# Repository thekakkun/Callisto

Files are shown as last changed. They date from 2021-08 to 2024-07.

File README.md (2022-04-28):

# Callisto

Callisto is a digital clock that uses a Russian IV-18 vacuum fluorescent tube for the display. The clock uses an ESP32 to automatically sync time.

The name *Callisto* was chosen so that the name could be displayed on an 8-digit seven-segment display.

DSC01592 (2)

## Features:
- Sync time, retrieved using WiFi
- Automatically switch to daylight saving time
- Clock display settings configured using web browser
- Automatic shutoff during night hours in order to decrease energy usage and extend tube life
- Auto-dimming based on ambient light conditions

## Special thanks

The software and hardware design of the clock was ~~stolen from~~ heavily inspired by the following projects:

- [Ice Tube Clock by Lady Ada](https://learn.adafruit.com/ice-tube-clock-kit/)
- [Flora-ESP8266 by mcer12](https://github.com/mcer12/Flora-ESP8266)

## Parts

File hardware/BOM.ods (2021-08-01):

Name | Value | Count | Added?
A1 | TSSOP-28 to DIP-28 | 1 | Yes
C1, C3, C5 | 0.1uF | 3 | Yes
C2, C7 | 47uF/25V | 2 | Yes
C4 | 220uF/6.3V | 1 | Yes
C6 | 22uF/100V | 1 | Yes
D1, D3 | MBR160 | 2 | Yes
F1 | 200mA | 1 | Yes
IC1 | ESP32-DevKit-C | 1 | Yes
IC2 | MAX6921AUI+ | 1 | Yes
IC3 | 7805T | 1 | Yes
J1 | 2.1mm power jack | 1 | Yes
L1 | 2200uH | 1 | Yes
Power | 9V power adaptor | 1 | Yes
Q2 | IRFD110PBF | 1 | No
Tube | IV-18 | 1 | Yes
Other items
Breadboard
cables
soldering iron
Solder

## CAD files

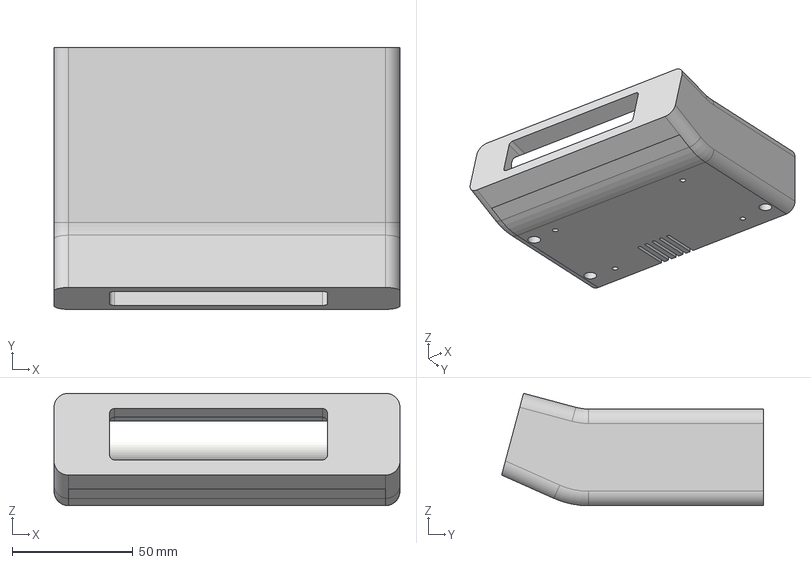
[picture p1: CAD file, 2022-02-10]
hardware/case/Callisto.step
143.0 x 108.2 x 46.5 mm
IV-18
Case Top
Tube PCB
Main PCB

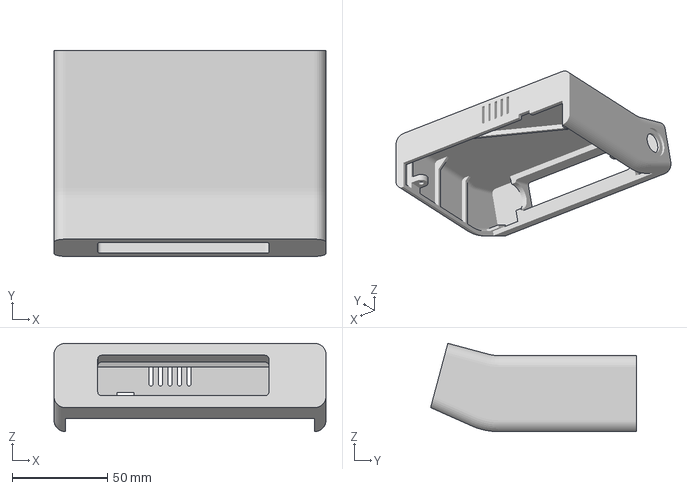
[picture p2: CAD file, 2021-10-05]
hardware/case/Case Top.3mf
143.0 x 108.2 x 46.5 mm

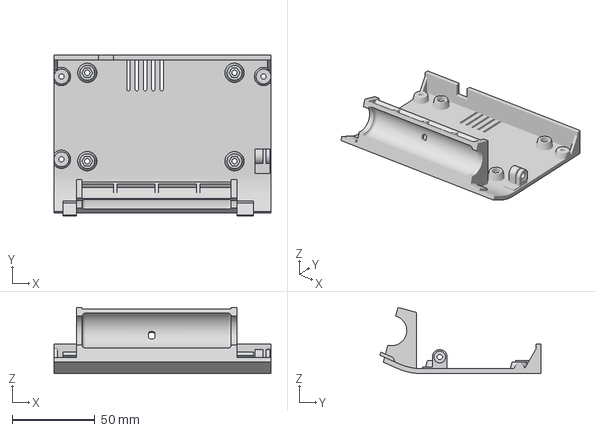
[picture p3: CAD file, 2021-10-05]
hardware/case/Case Bottom.3mf
131.0 x 97.2 x 39.9 mm

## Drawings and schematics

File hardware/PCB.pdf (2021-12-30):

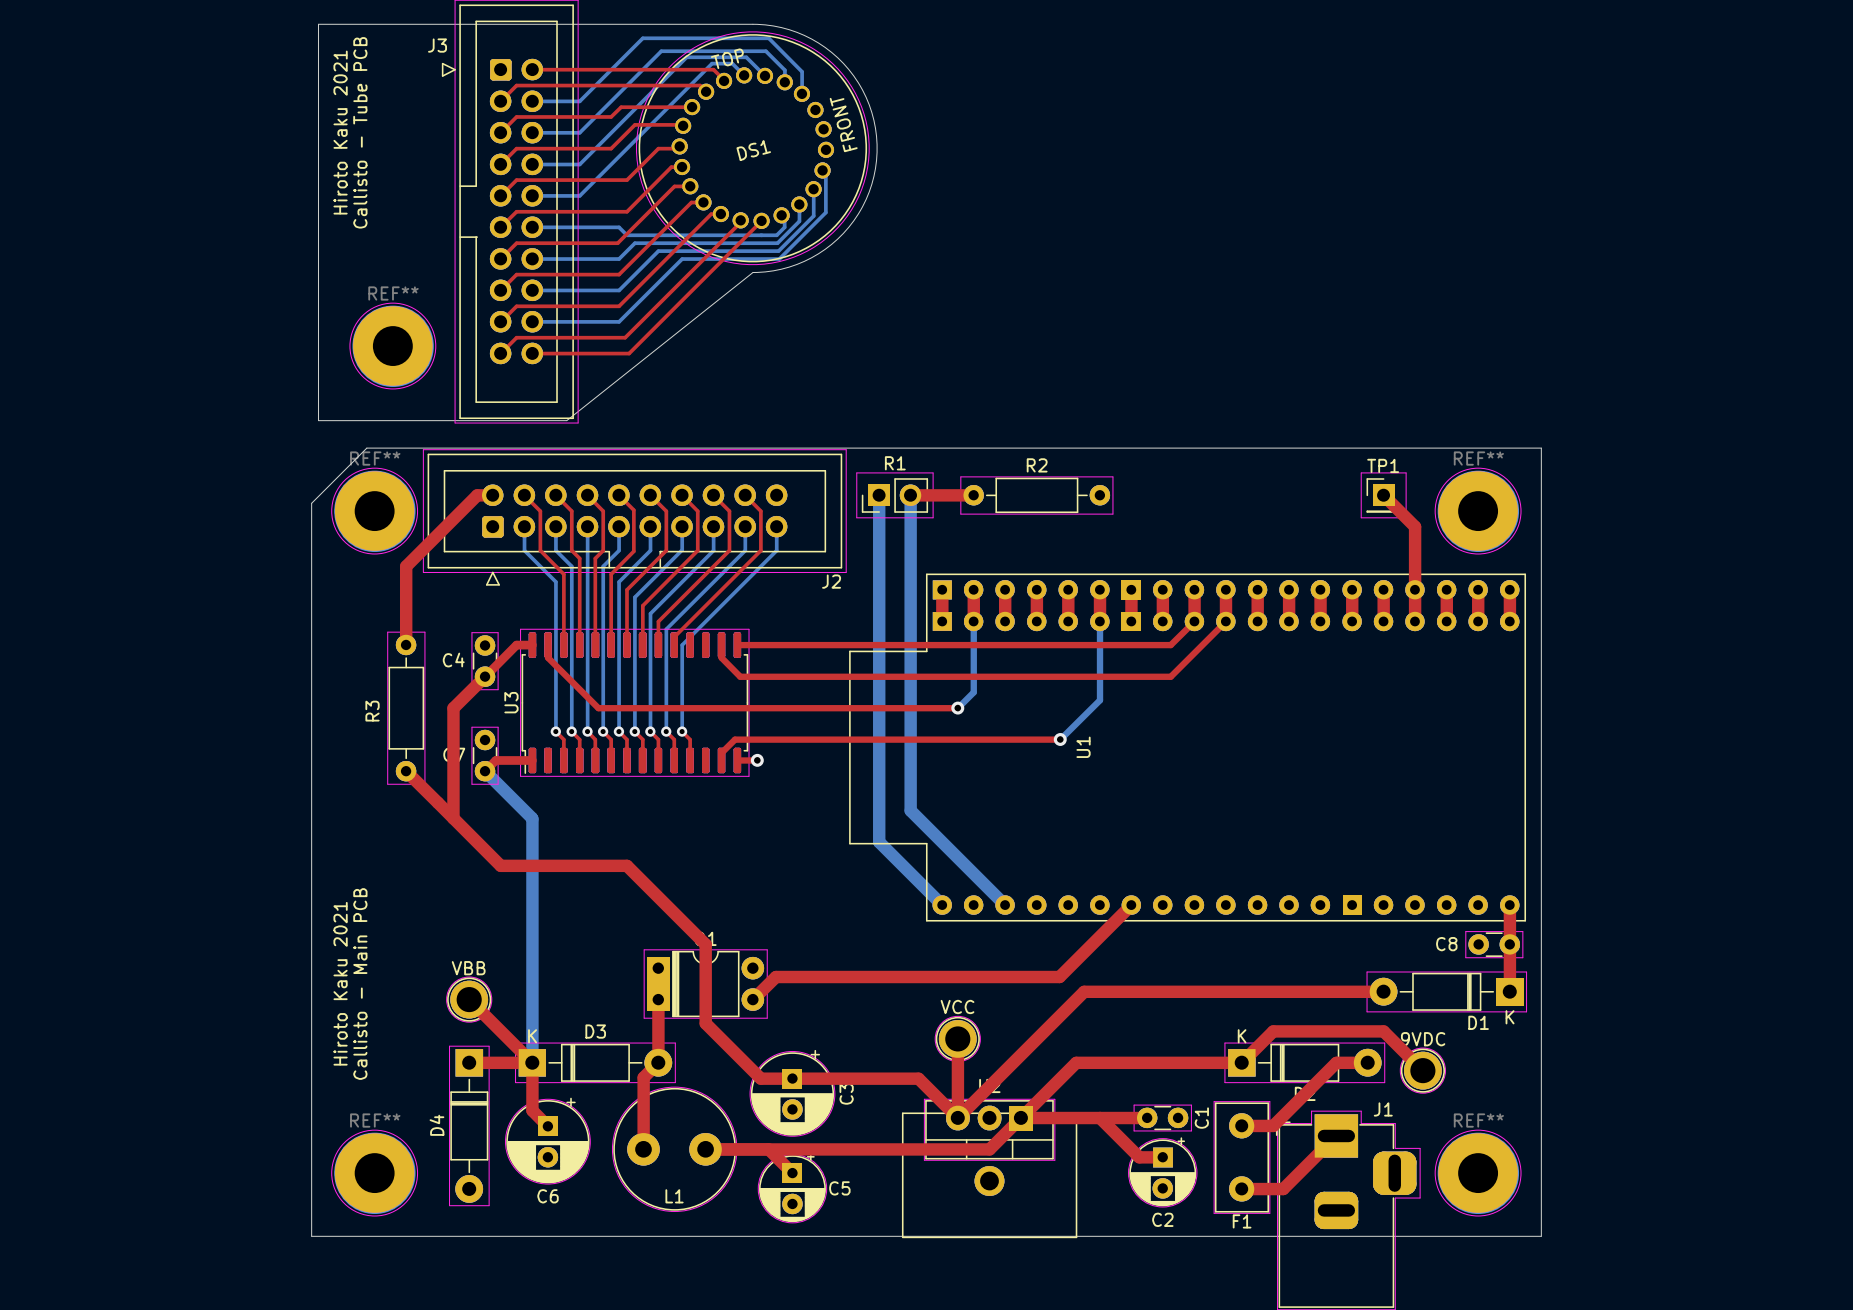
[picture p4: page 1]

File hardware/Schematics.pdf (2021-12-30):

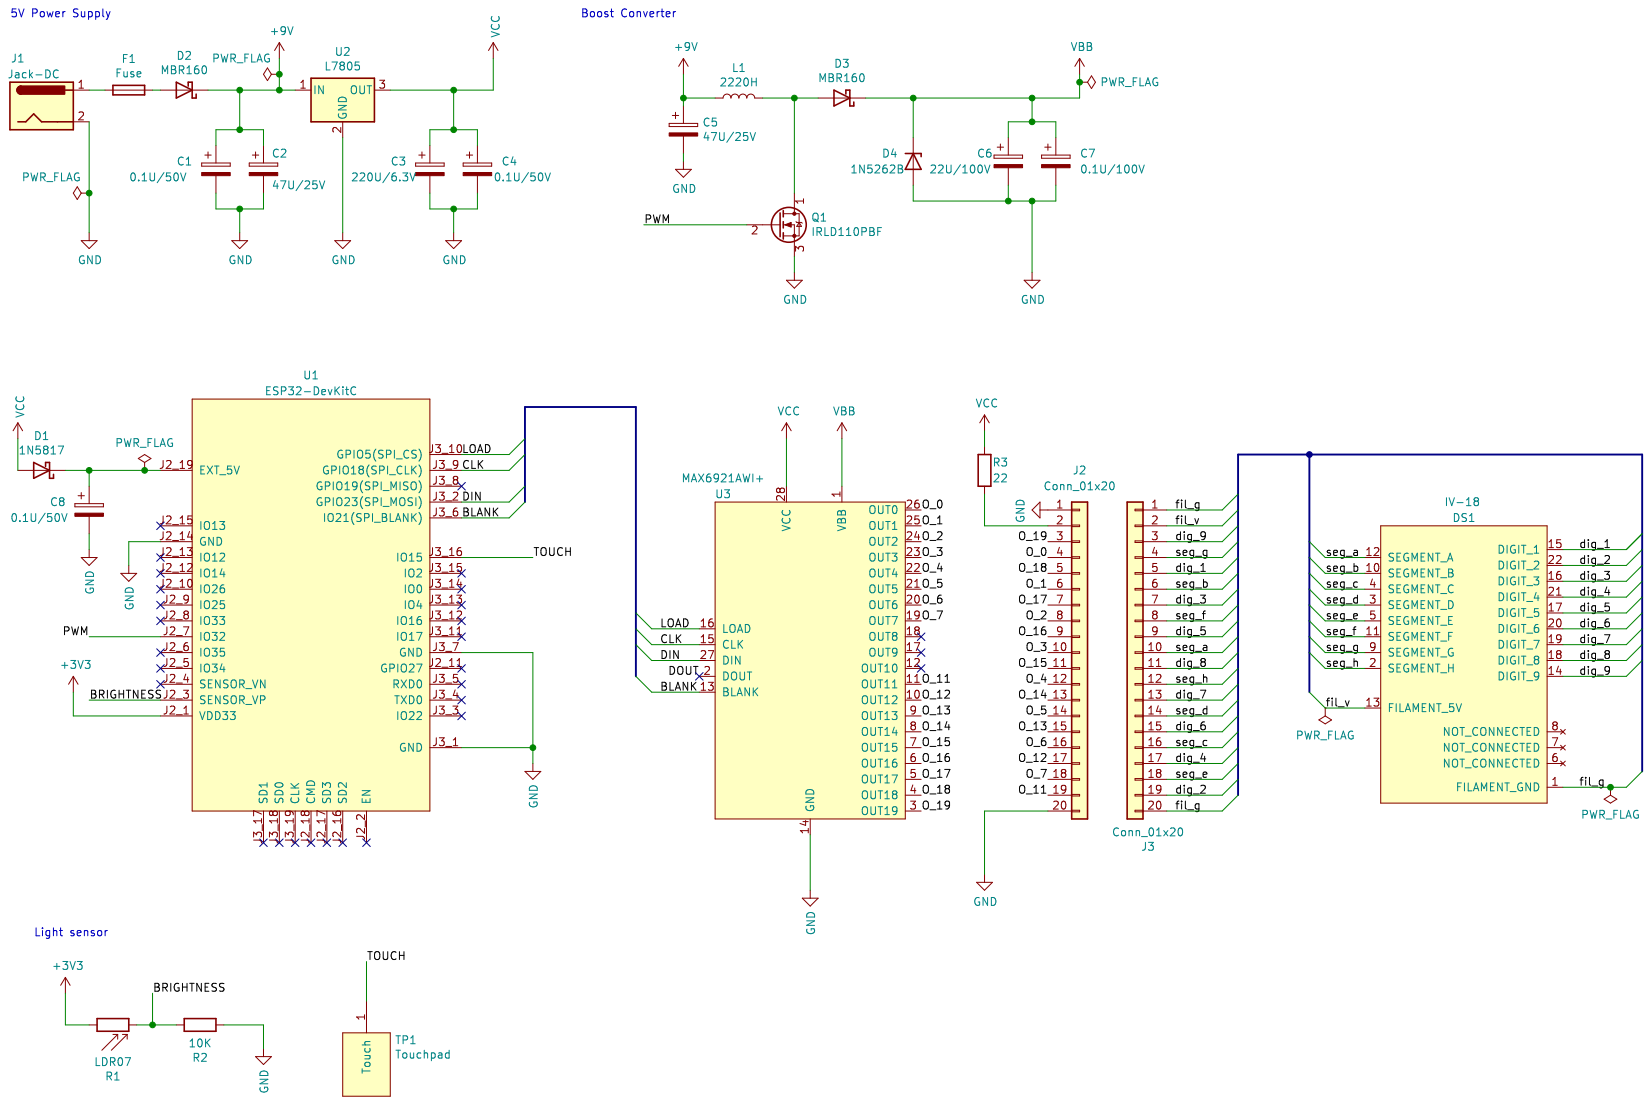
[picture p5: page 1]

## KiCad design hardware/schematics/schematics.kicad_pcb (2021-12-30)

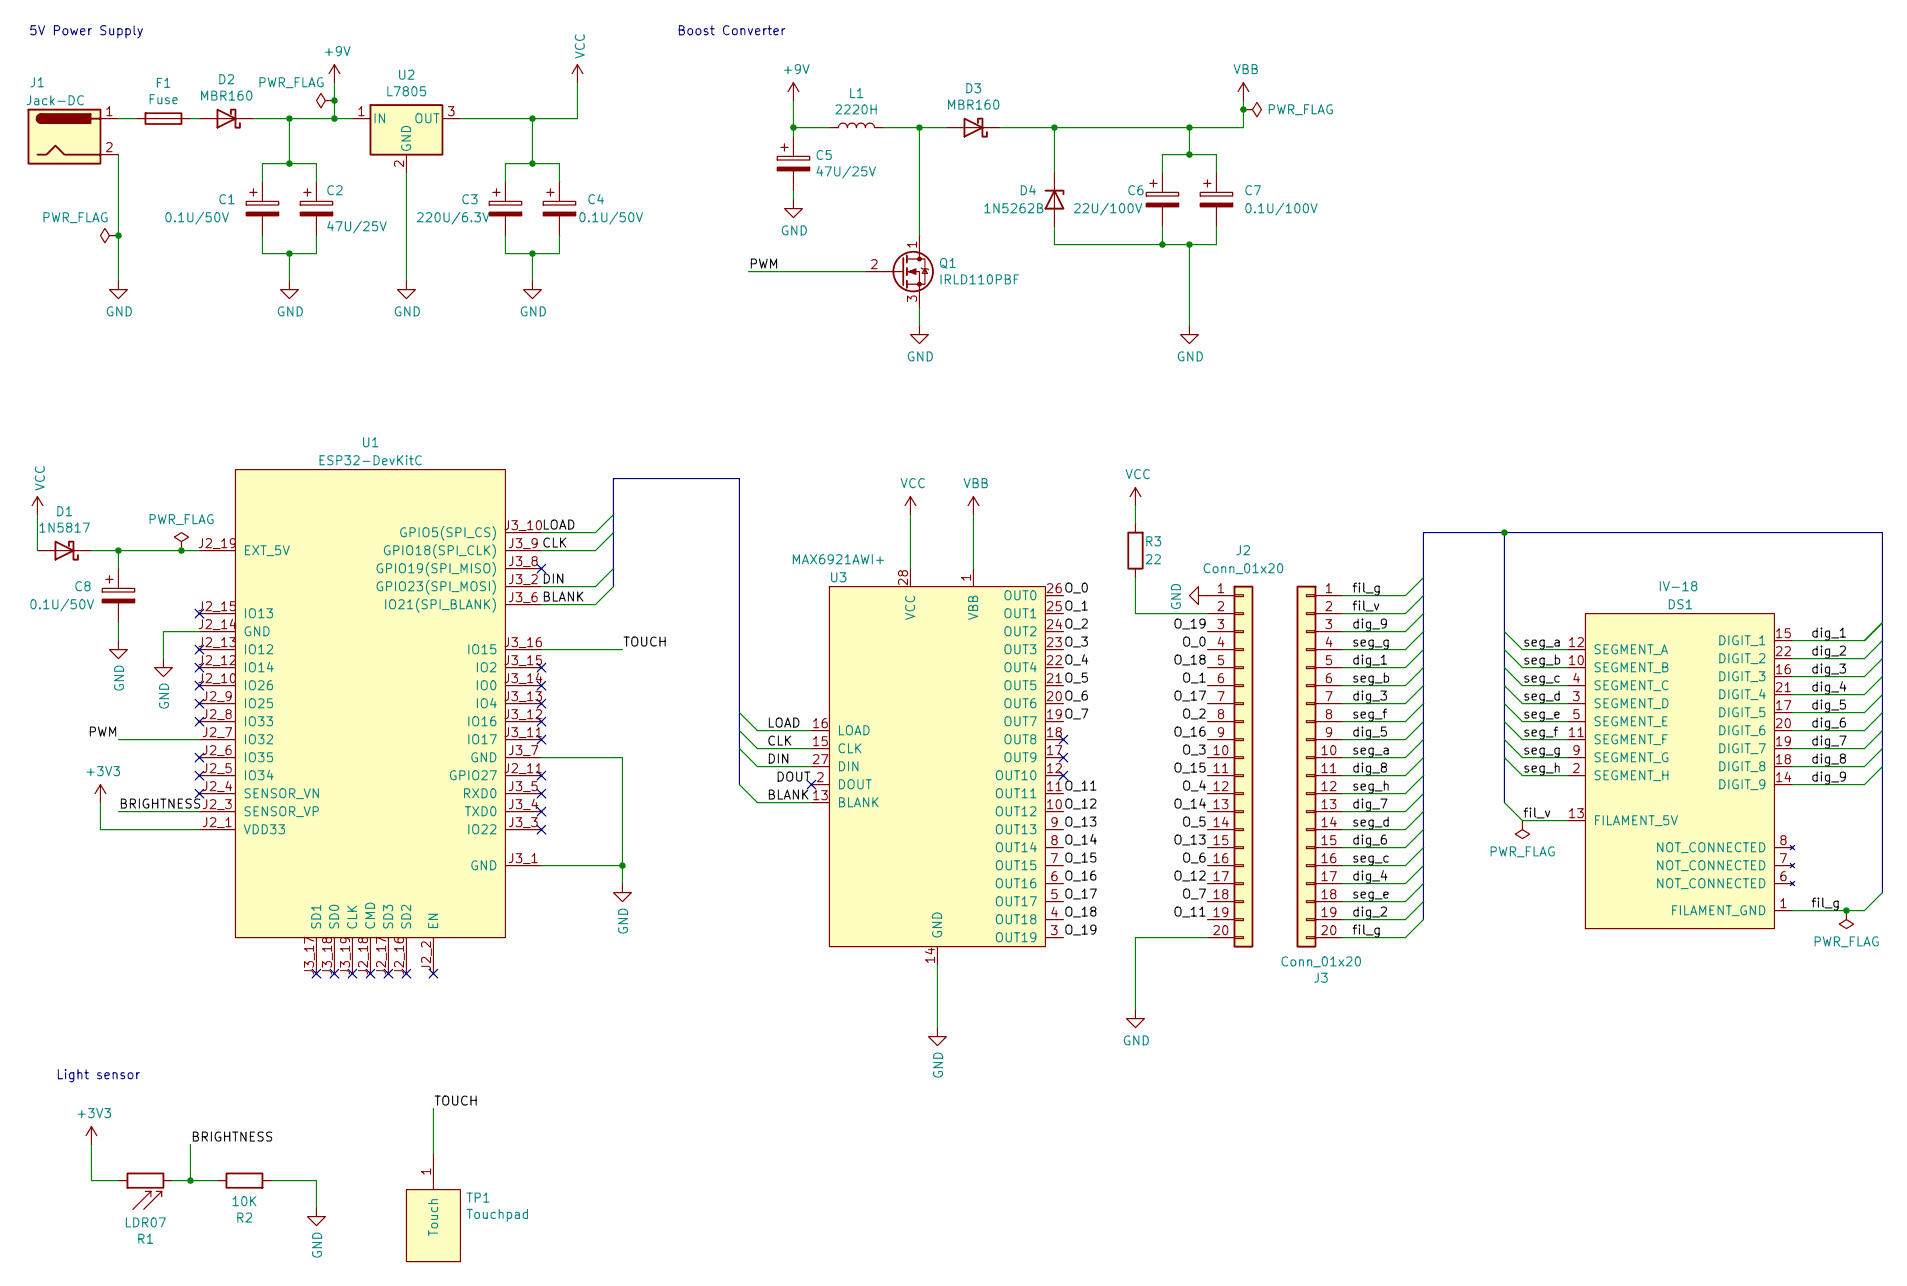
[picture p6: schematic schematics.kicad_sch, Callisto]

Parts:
C1, C4, C8: 0.1U/50V; C_Disc_D3.0mm_W1.6mm_P2.50mm
C2, C5: 47U/25V; CP_Radial_D5.0mm_P2.50mm
C3: 220U/6.3V; CP_Radial_D6.3mm_P2.50mm
C6: 22U/100V; CP_Radial_D6.3mm_P2.50mm
C7: 0.1U/100V; C_Disc_D3.0mm_W1.6mm_P2.50mm
D1: 1N5817; D_DO-41_SOD81_P10.16mm_Horizontal
D2, D3: MBR160; D_DO-41_SOD81_P10.16mm_Horizontal
D4: 1N5262B; D_DO-41_SOD81_P10.16mm_Horizontal
DS1: IV-18
F1: Fuse; Fuse_Littelfuse_395Series
J1: Jack-DC; BarrelJack_Horizontal
J2, J3: Conn_01x20; IDC-Header_2x10_P2.54mm_Vertical
L1: 2220H; L_Radial_D9.5mm_P5.00mm_Fastron_07HVP
Q1: IRLD110PBF; Vishay_HVM-DIP-3_W7.62mm
R1: LDR07; PinHeader_1x02_P2.54mm_Vertical
R2: 10K; R_Axial_DIN0207_L6.3mm_D2.5mm_P10.16mm_Horizontal
R3: 22; R_Axial_DIN0207_L6.3mm_D2.5mm_P10.16mm_Horizontal
TP1: Touchpad; PinHeader_1x01_P2.54mm_Vertical
U1: ESP32-DevKitC; ESP32 DevKitC
U2: L7805; L7805_with_heatsink
U3: MAX6921AWI+; SOIC-28W_7.5x17.9mm_P1.27mm

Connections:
+3V3: R1.1, U1.J2_1 (VDD33)
+9V: C1.1, C2.1, C5.1, D2.1 (K), L1.1, U2.1 (IN); also elsewhere on the board
/BLANK: U1.J3_6 (IO21(SPI_BLANK)), U3.13 (BLANK)
/BRIGHTNESS: R1.2, R2.1, U1.J2_3 (SENSOR_VP)
/CLK: U1.J3_9 (GPIO18(SPI_CLK)), U3.15 (CLK)
/DIN: U1.J3_2 (GPIO23(SPI_MOSI)), U3.27 (DIN)
/DOUT: U3.2 (DOUT)
/LOAD: U1.J3_10 (GPIO5(SPI_CS)), U3.16 (LOAD)
/O_0: J2.4, U3.26 (OUT0)
/O_1: J2.6, U3.25 (OUT1)
/O_2: J2.8, U3.24 (OUT2)
/O_3: J2.10, U3.23 (OUT3)
/O_4: J2.12, U3.22 (OUT4)
/O_5: J2.14, U3.21 (OUT5)
/O_6: J2.16, U3.20 (OUT6)
/O_7: J2.18, U3.19 (OUT7)
/O_11: J2.19, U3.11 (OUT11)
/O_12: J2.17, U3.10 (OUT12)
/O_13: J2.15, U3.9 (OUT13)
/O_14: J2.13, U3.8 (OUT14)
/O_15: J2.11, U3.7 (OUT15)
/O_16: J2.9, U3.6 (OUT16)
/O_17: J2.7, U3.5 (OUT17)
/O_18: J2.5, U3.4 (OUT18)
/O_19: J2.3, U3.3 (OUT19)
/PWM: Q1.2 (G), U1.J2_7 (IO32)
/TOUCH: TP1.1, U1.J3_16 (IO15)
/dig_1: DS1.15 (DIGIT_1), J3.5
/dig_2: DS1.22 (DIGIT_2), J3.19
/dig_3: DS1.16 (DIGIT_3), J3.7
/dig_4: DS1.21 (DIGIT_4), J3.17
/dig_5: DS1.17 (DIGIT_5), J3.9
/dig_6: DS1.20 (DIGIT_6), J3.15
/dig_7: DS1.19 (DIGIT_7), J3.13
/dig_8: DS1.18 (DIGIT_8), J3.11
/dig_9: DS1.14 (DIGIT_9), J3.3
/fil_g: DS1.1 (FILAMENT_GND), J3.1, J3.20
/fil_v: DS1.13 (FILAMENT_5V), J3.2
/seg_a: DS1.12 (SEGMENT_A), J3.10
/seg_b: DS1.10 (SEGMENT_B), J3.6
/seg_c: DS1.4 (SEGMENT_C), J3.16
/seg_d: DS1.3 (SEGMENT_D), J3.14
/seg_e: DS1.5 (SEGMENT_E), J3.18
/seg_f: DS1.11 (SEGMENT_F), J3.8
/seg_g: DS1.9 (SEGMENT_G), J3.4
/seg_h: DS1.2 (SEGMENT_H), J3.12
GND: C1.2, C2.2, C3.2, C4.2, C5.2, C6.2, C7.2, C8.2, D4.2 (A), J1.2, J2.1, J2.20, Q1.3 (S), R2.2, U1.J2_14 (GND), U1.J3_1 (GND), U1.J3_7 (GND), U2.2 (GND), U3.14 (GND)
unnamed: C8.1, D1.1 (K), U1.J2_19 (EXT_5V)
unnamed: D2.2 (A), F1.1
unnamed: D3.2 (A), L1.2, Q1.1 (D)
unnamed: F1.2, J1.1
unnamed: J2.2, R3.1
VBB: C6.1, C7.1, D3.1 (K), D4.1 (K), U3.1 (VBB); also elsewhere on the board
VCC: C3.1, C4.1, D1.2 (A), R3.2, U2.3 (OUT), U3.28 (VCC); also elsewhere on the board

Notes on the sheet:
5V Power Supply
Light sensor
Boost Converter

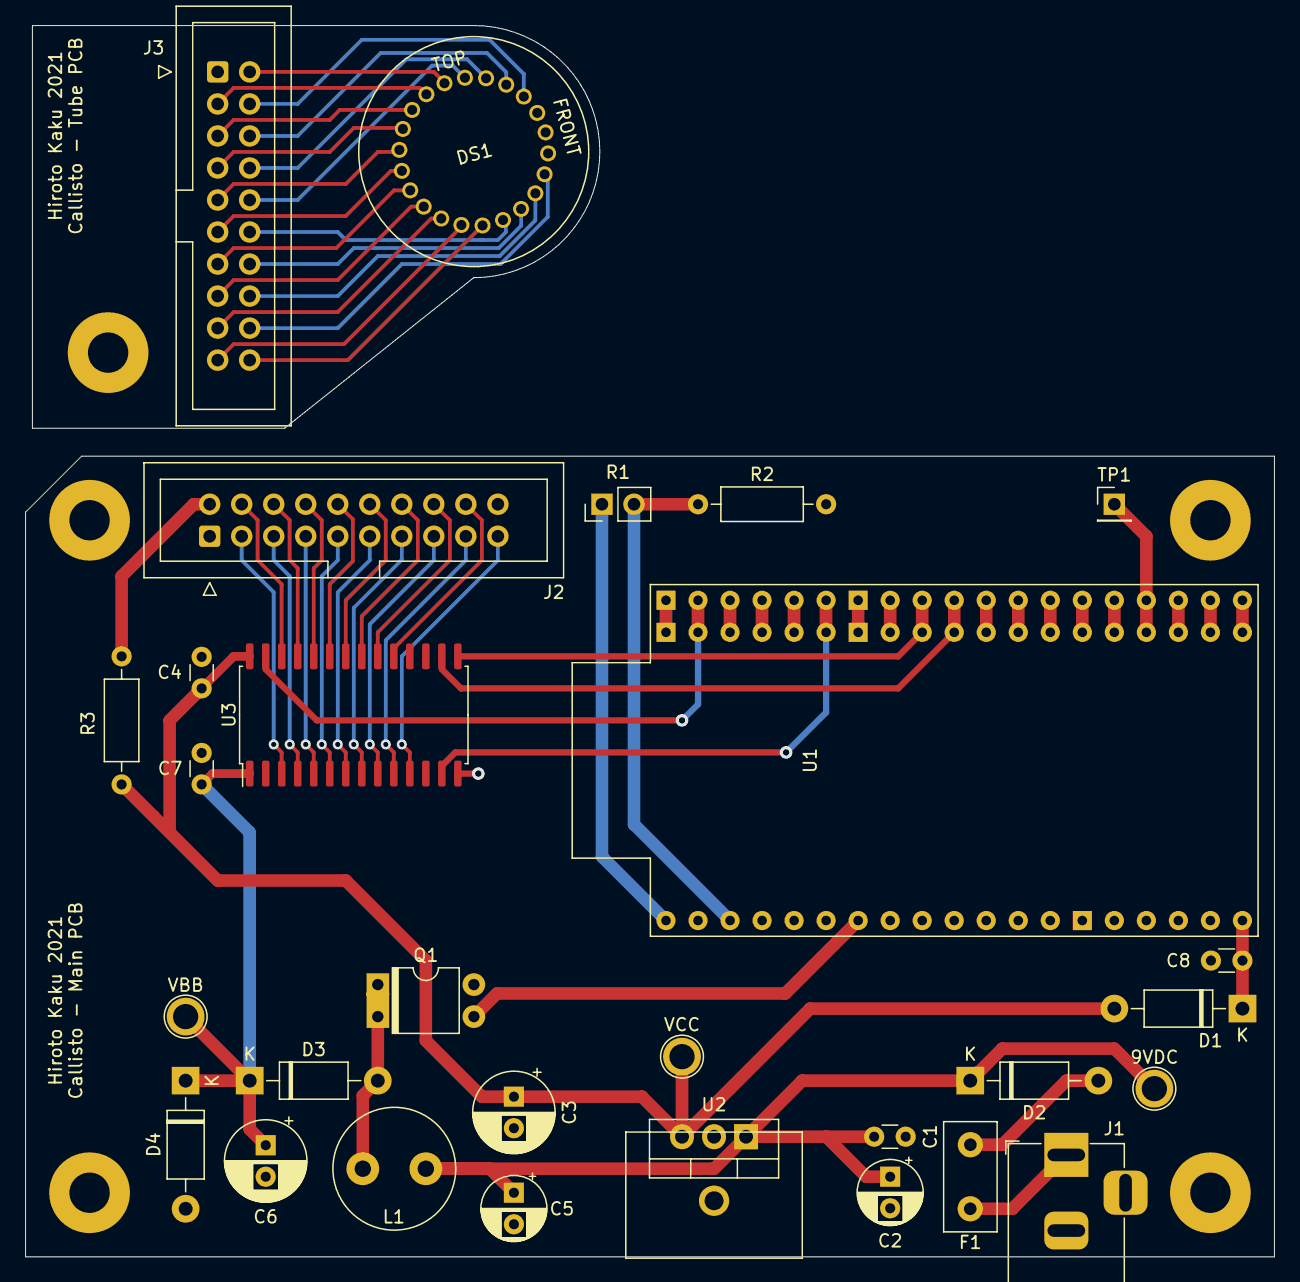
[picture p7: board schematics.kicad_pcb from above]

Board: 2 copper layers, 99.1 x 97.7 mm, 29 parts (0 on the bottom side), 53 nets.

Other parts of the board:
9VDC: TestPoint_Plated_Hole_D2.0mm
VBB: TestPoint_Plated_Hole_D2.0mm
VCC: TestPoint_Plated_Hole_D2.0mm

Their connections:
+9V: 9VDC.1; also elsewhere on the board
VBB: VBB.1; also elsewhere on the board
VCC: VCC.1; also elsewhere on the board

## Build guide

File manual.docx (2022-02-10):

# Operating Instructions for Callisto

# 1. Features

Callisto is a clock that uses a Russian IV-18 vacuum fluorescent display (VFD) tube as the indicator.

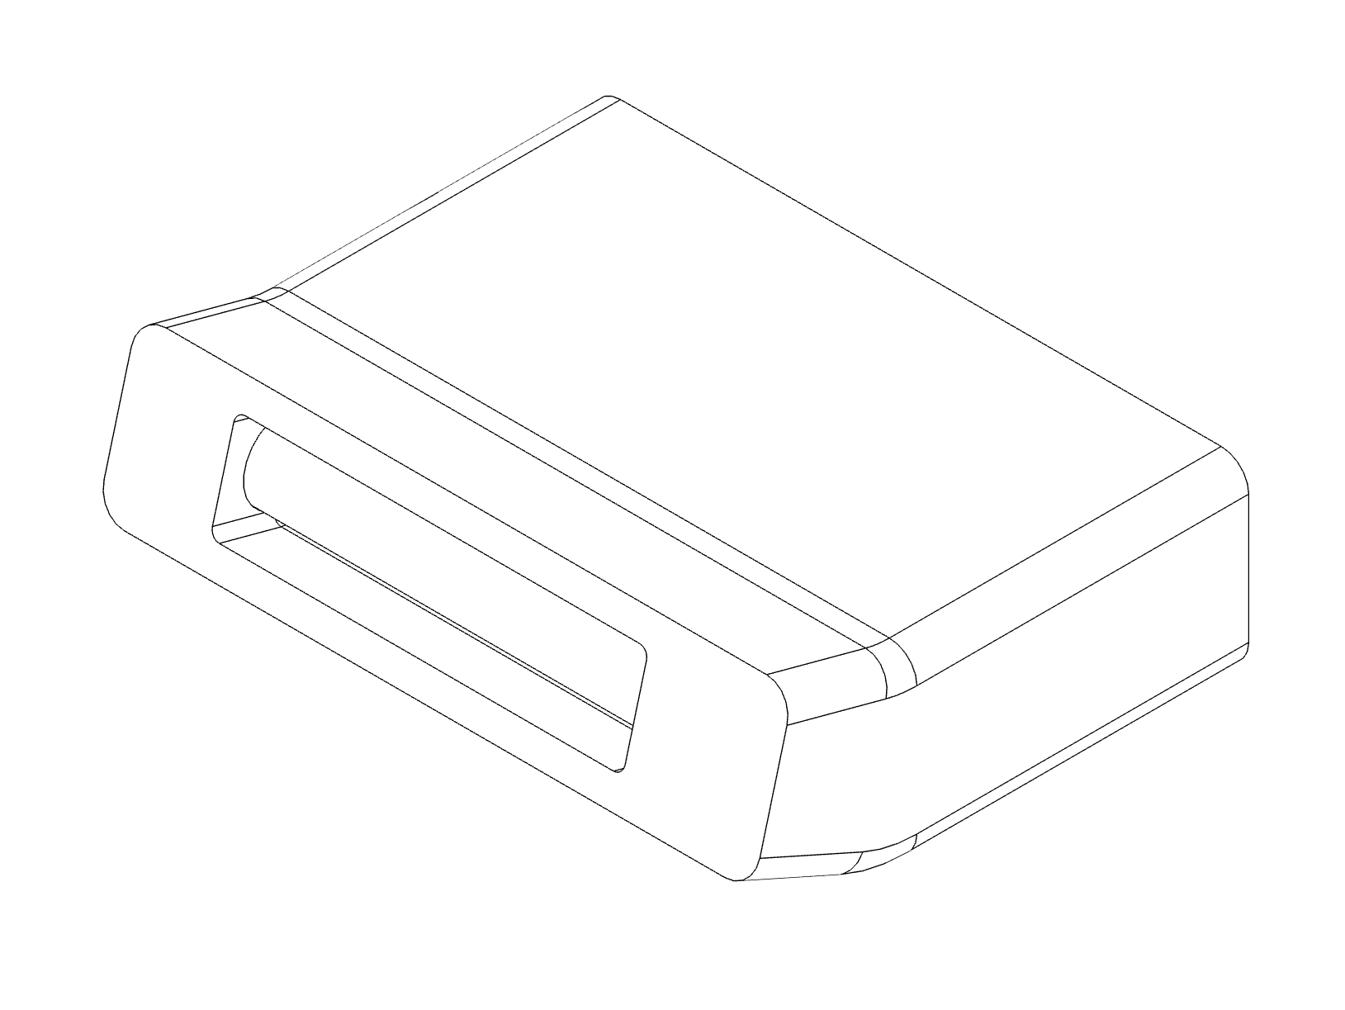
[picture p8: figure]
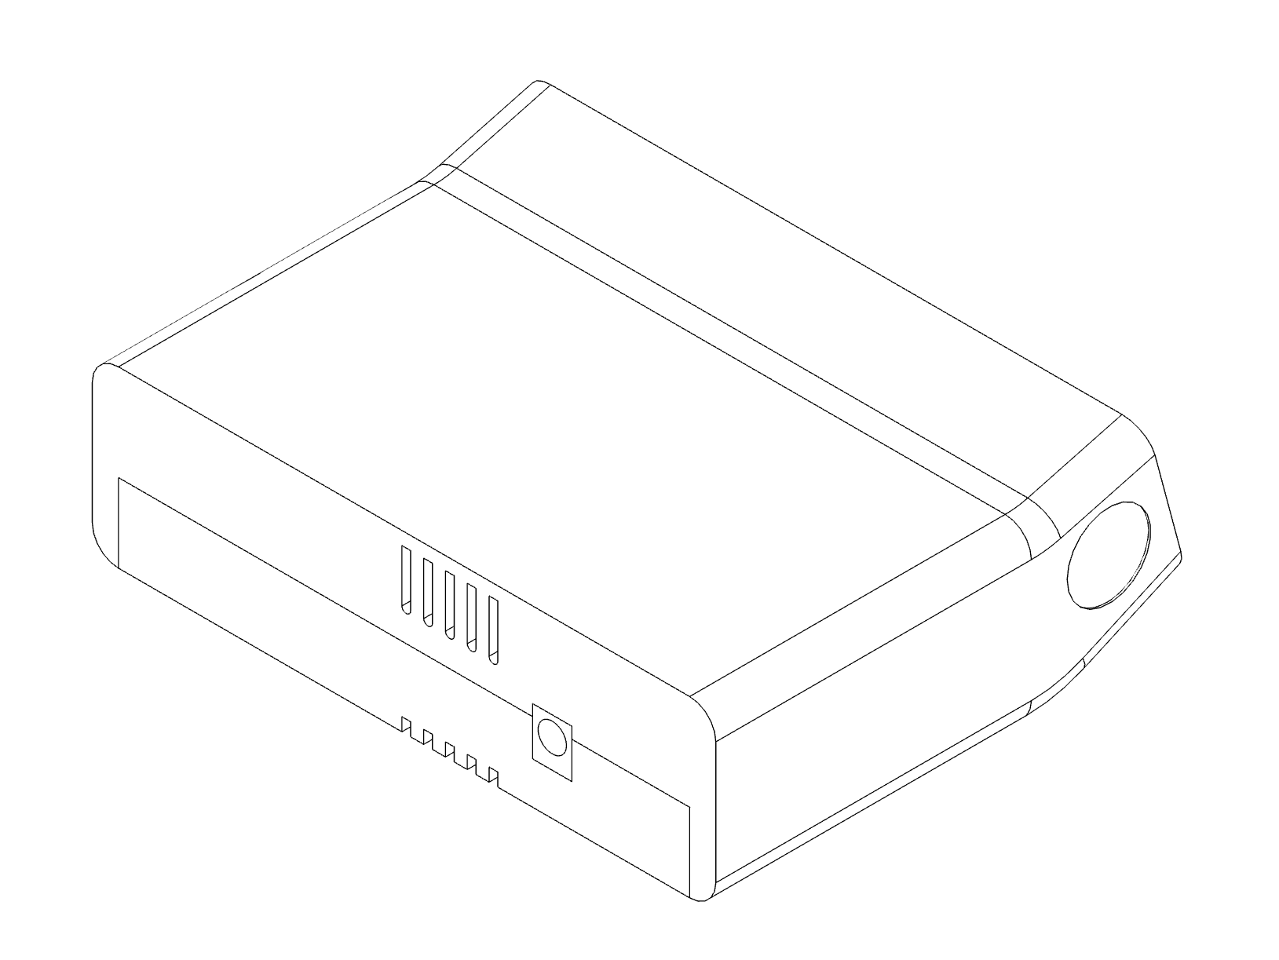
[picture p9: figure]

Touch pad

DC power jack

Vacuum fluorescent display

- Vacuum fluorescent display
  - Glowy!
  - Displays the time!
  - Auto-dims based on ambient light conditions.
- DC power jack
  - Use a 9V AC to DC wall adapter to power the clock.
- Touch pad
  - During normal operation, tap to display the time.
  - During night mode, tap to momentarily wake up Callisto and display the time.
  - Tap and hold to enter configuration mode.
- Other Features
  - Time sync: Connects to Wi-Fi to retrieve the time. Automatically adjusts for daylight saving time.
  - Night mode: Turns off from 12 midnight to 6 AM to conserve energy and prolong tube life.

# 2. Initial Setup

1. Plug in Callisto using a 9V AC to DC wall adapter.
2. The display should show . Callisto is ready to be connected to Wi-Fi.
3. Using a PC or smartphone, connect to the Wi-Fi access point named callisto_config. Use the password 12345678 to connect.
4. A web browser should open automatically. Enter the Wi-Fi details for the network you want Callisto to use.

Note: Callisto can only connect to 2.4 GHz Wi-Fi networks.

5. Click on “save and reboot.” If Callisto does not reboot, and display still shows , try refreshing the browser window to resend the data. If that does not work, go back to step 3.
6. Callisto should now connect to Wi-Fi and synchronize and the time.

Note: All settings, including Wi-Fi credentials will remain saved, even when unplugged.

7. To change time zone settings or other display format options, continue to 4. Configuration.

# 3. Display Modes

Mode | Display | Notes
Synchronizing time | | Callisto has successfully connected to Wi-Fi and is syncing the clock.
Time | | The current time.
Date | | The current date. To show the date, tap the touch pad. The date will display for 5 seconds before returning to the time.
Configuration | | See 4. Configuration for steps to configure Callisto. In configuration mode, a 2- or 3-digit number will be shown, indicating the last digits of Callisto’s IP address.
Wi-Fi error | | Callisto was unable to connect to Wi-Fi. See 5. Troubleshooting for details.
Initial setup | | Callisto needs to be set up. See 2. Initial Setup for details.

# 4. Configuration

1. To enter configuration mode, tap and hold the touch pad for 10 seconds.

Note: If in night mode (by default from midnight to 6 AM), tap to wake Callisto. Once the time is displayed, release the touch pad, and hold down for 10 seconds.

2. If successful, the display should no longer display the time, and instead show a 2- or 3-digit number. This number is the last digit of Callisto’s IP address.
3. Using a PC or smartphone connected to the same network as Callisto, open a browser and enter 192.168.0.XXX in the address bar, replacing the XXX with the number displayed on Callisto.

Note: This will not work if you’ve changed your default gateway address to something other than 192.168.0.1. If you’ve done that, you can probably figure out what needs to be done here.

4. You can use the page to change display settings for Callisto.

Note: Callisto isn’t very fast and may run into issues showing you the configuration page. If the page doesn’t load, try refreshing your browser.

5. Use the buttons at the bottom of the page to save, cancel, or reset to factory settings. The browser window should show a message, indicating success.

Note: If Callisto is still showing the IP address after saving, cancelling, or resetting, try re-sending the data by refreshing the browser window.

## 4.1. Configuration Details

### Network

#### Wi-Fi SSID

The name of the network Callisto is connected to.

#### Wi-Fi password

Password for the Wi-Fi network.

### Time Display

#### Hour format

How AM/PM is displayed.

Setting | Display
12-hour (PM dot)
12-hour (no PM dot)
24-hour

#### Padding

Show/hide leading zero.

Setting | Display
No pad
Zero pad

#### Dividers

Display symbols between digits.

Setting | Display
Space
Hyphen

### Date Display

#### Display format

Day/month/year order.

Setting | Display
Month, Day, Year
Day, Month, Year

#### Padding

Show/hide leading zero.

Setting | Display
No pad
Zero pad

#### Dividers

Display symbols between digits.

Setting | Display
Dot, full year
Hyphen
Space

### Brightness

Callisto will automatically adjust display brightness based on ambient light.

Note: Allow 24 hours after booting for Callisto to learn how bright/dark it gets in your room.

### Night Mode

The display turns off at night to extend the tube’s life. Default night hours are from midnight to 6 AM but can be configured here.

Note: Wake-up time and the time displayed when tapping the touch pad during night mode hours may be inaccurate by several minutes. This is because Callisto will enter deep sleep mode during night hours and will use a less accurate time-keeping method. Expect time to be a few minutes off during night mode hours. Time will be re-synced once night mode ends.

### Time Zone

The time zone for Callisto is specified using the POSIX format. Click on the link to see some common time zones.

### Factory Reset

This will reset everything to factory defaults, including Wi-Fi credentials, and cannot be undone!

# 5. Troubleshooting

Callisto was designed by someone who wasn’t quite sure if they were doing the right things. When using Callisto, be patient!

When troubleshooting, first try rebooting Callisto by unplugging and plugging it back in. If that doesn’t work, check the table below potential solutions.

Problem | Solution
The display is blank | - Check if Callisto is plugged in. You should be able to see a red LED inside the case, from the back vents. - Display will initially be blank while Callisto boots and connects to Wi-Fi. Wait for 10 seconds to see if anything shows up. - Callisto will turn off the display at night to extend the tube’s life. Default night hours are from 12 midnight to 6 AM.
Display shows | - Callisto timed out while trying to connect to Wi-Fi. Try rebooting it first. - If problem persists, the Wi-Fi credentials may be incorrect. With Callisto plugged in and displaying , use a PC or smartphone, search for the Wi-Fi access point named callisto_config, and use the password 12345678 to connect. A browser window should open automatically. Re-enter your Wi-Fi credentials and save.
Display is stuck showing | - Callisto has successfully connected to Wi-Fi but may be having trouble syncing the time. Wait for 5 minutes to see if the issue resolves itself.
The time and/or date is incorrect | - Check to see if the time zone has been configured correctly. See 4. Configuration for details. - Callisto will use a less accurate time-keeping method during night mode hours. Expect time to be off by several minutes during night mode. Time will automatically re-sync once night mode ends.

If none of the above work, Callisto may be broken! Please send in any issues you find to Callisto’s GitHub page: https://github.com/thekakkun/Callisto/issues.

# 6. Miscellaneous

See source code, get hardware specifications, and contact me at GitHub:
https://github.com/thekakkun/Callisto

Heavily inspired by the following projects, so thank you!

- Ice Tube Clock by Lady Ada (https://learn.adafruit.com/ice-tube-clock-kit/)
- Flora-ESP8266 by mcer12 (https://github.com/mcer12/Flora-ESP8266)

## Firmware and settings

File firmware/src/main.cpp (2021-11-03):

#include <Arduino.h>
#include <esp32-hal-touch.h>
#include <movingAvg.h>

#include "init.h"
#include "config_server.h"
#include "display.h"

// Flags
RTC_DATA_ATTR int boot_count{0};
RTC_DATA_ATTR bool credentials_saved{false};
RTC_DATA_ATTR bool wifi_connected{false};
RTC_DATA_ATTR bool time_synced{false};
bool ap_active{false};
bool server_active{false};

// PWM and photoresistor
constexpr int LDR_PIN{36};
constexpr int BOOST_CHANNEL{0};
movingAvg ldr_reading(50);
RTC_DATA_ATTR int min_brightness{4095};
RTC_DATA_ATTR int max_brightness{0};

RTC_DATA_ATTR unsigned long last_brightness_damper{0};
RTC_DATA_ATTR unsigned long last_wifi_check{0};

// Touch
constexpr int TOUCH_THRESHOLD{400};
unsigned long touch_wake_time{};

// SPI interface
constexpr int VFLOAD{5};
constexpr int BLANK_CHANNEL{2};
constexpr int VFBLANK{21};

// Font Table
int font_table[46]{};
int digit_table[9]{};
int dot{};

DNSServer dns_server;
AsyncWebServer server(80);
CallistoSettings settings;
String ssid_options;

void setup()
{
  Serial.begin(115200);

  init_brightness();
  init_touch();
  init_spi();
  init_spiffs();
  init_font_table();
  settings.init();

  if (settings.ssid.compareTo("") != 0)
  {
    credentials_saved = true;
  }

  esp_sleep_wakeup_cause_t wakeup_reason;
  wakeup_reason = esp_sleep_get_wakeup_cause();

  if (wakeup_reason == ESP_SLEEP_WAKEUP_TOUCHPAD)
  {
    touch_wake_time = millis();
  }
  else
  {
    if (credentials_saved)
    {
      init_wifi();
    }

    if (wifi_connected)
    {
      init_power_save();
      init_sntp();
    }
    else if (boot_count)
    {
      init_power_save();
      time_synced = true;
      wifi_connected = true;
    }
  }

  ++boot_count;
}

void loop()
{
  static int current_digit{0};
  static char disp_text[10]{};
  int dots[9]{};

  // Get ambient light and adjust PWM
  utilities(&min_brightness, &max_brightness);
  adjust_brightness(min_brightness, max_brightness);

  // Set display text and dots based on mode
  Mode disp_mode{get_mode()};
  set_text(disp_mode, disp_text);
  set_dots(disp_mode, dots);

  //  Send digit via SPI
  int spi_data{get_spi_data(current_digit, disp_text, dots)};
  send_spi_data(spi_data);

  ++current_digit;
  current_digit %= 9;
}

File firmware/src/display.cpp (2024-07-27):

#include "config_server.h"
#include "display.h"
#include <driver/touch_sensor.h>
#include <soc/touch_sensor_channel.h>

void adjust_brightness(int min_brightness, int max_brightness)
{
    /* Set the anode voltage based on ambient brightness.
   * Target voltages used in the calculation do not reflect actual boost
   * converter outputs for whatever reason...
   */

    // Gives max tube voltage of 48-ish volts. Increase value for higher voltage at risk of decreased tube life.
    constexpr int BOOST_DUTY{160};
    constexpr int PWM_LIM_HI{0}, PWM_LIM_LO{240}; // Absolute limits for PWM.
    const int PWM_LIM_RANGE{PWM_LIM_LO - PWM_LIM_HI};
    float pwm_hi, pwm_lo;
    float brightness_p{};
    int blank_duty;

    // PWM limit based on user-set brightness range.
    pwm_hi = PWM_LIM_HI + (PWM_LIM_RANGE * static_cast<float>(settings.lo_brightness - 1) / 9);
    pwm_lo = PWM_LIM_HI + (PWM_LIM_RANGE * static_cast<float>(settings.hi_brightness - 1) / 9);

    int brightness{analogRead(LDR_PIN)};
    int brightness_avg{ldr_reading.reading(brightness)};
    brightness_p =
        static_cast<float>(brightness_avg - min_brightness) / (max_brightness - min_brightness);
    blank_duty = static_cast<int>(pwm_hi + (1 - brightness_p) * (pwm_lo - pwm_hi));

    ledcWrite(BOOST_CHANNEL, BOOST_DUTY);
    ledcWrite(BLANK_CHANNEL, blank_duty);
}

void set_touch_state(bool &touch_state, bool &previous_touch_state,
                     unsigned long &touch_start, unsigned long &touch_end)
{
    /* Figure out when touch starts and ends, and set the time in ms.
   */

    uint16_t touch_value{};
    unsigned long now_ms{millis()};

    touch_pad_read_filtered(TOUCH_PAD_GPIO15_CHANNEL, &touch_value);

    if (touch_value < TOUCH_THRESHOLD)
    {
        touch_state = true;

        if (!previous_touch_state)
        {
            touch_start = now_ms;
            Serial.println("Touch start");
        }
    }
    else
    {
        touch_state = false;

        if (previous_touch_state)
        {
            touch_end = now_ms;
            Serial.println("Touch end");
        }
    }
}

bool is_night(bool touch_state = false)
{
    /* Figure out if night mode should be active
   */

    if (touch_state)
    {
        return false;
    }
    else
    {
        time_t now{time(0)};
        struct tm timeinfo = *localtime(&now);

        int current_time_digital{};
        static int night_start_digital{}, night_end_digital{};

        current_time_digital = timeinfo.tm_hour * 100 + timeinfo.tm_min;
        night_start_digital =
            settings.night_start_h * 100 + settings.night_start_m;
        night_end_digital = settings.night_end_h * 100 + settings.night_end_m;

        if (night_start_digital == night_end_digital)
        {
            return false;
        }
        else if (night_start_digital < night_end_digital)
        {
            if (night_start_digital <= current_time_digital && current_time_digital < night_end_digital)
            {
                return true;
            }
            else
            {
                return false;
            }
        }
        else
        {
            if (night_start_digital <= current_time_digital || current_time_digital < night_end_digital)
            {
                return true;
            }
            else
            {
                return false;
            }
        }
    }
}

void go_to_sleep()
{
    time_t now;
    struct tm timeinfo;
    int time_digital, night_end_digital, deep_sleep_sec;

    Serial.println("entering sleep");

    now = time(0);
    timeinfo = *localtime(&now);

    time_digital = timeinfo.tm_hour * 100 + timeinfo.tm_min;
    night_end_digital = settings.night_end_h * 100 + settings.night_end_m;

    if (time_digital < night_end_digital)
    {
        deep_sleep_sec = (settings.night_end_h - timeinfo.tm_hour) * 60 * 60 +
                         (settings.night_end_m - timeinfo.tm_min) * 60 +
                         (0 - timeinfo.tm_sec);
    }
    else
    {
        deep_sleep_sec =
            (settings.night_end_h - timeinfo.tm_hour + 24) * 60 * 60 +
            (settings.night_end_m - timeinfo.tm_min) * 60 +
            (0 - timeinfo.tm_sec);
    }

    esp_deep_sleep(deep_sleep_sec * 1e6);
}

Mode get_mode()
{
    /* Get display mode based on success flags, current time, and touch reading
   */

    constexpr unsigned int SHOW_FOR{5 * 1000};
    constexpr unsigned int SERVER_START{10 * 1000};
    constexpr unsigned int SERVER_TIMEOUT{10 * 60 * 1000};

    unsigned long now_ms{};
    static bool touch_state{false};
    bool previous_touch_state{touch_state};
    static unsigned long touch_start{0}, touch_end{0};
    static unsigned long server_start_time{};

    if (!wifi_connected)
    {
        if (credentials_saved)
        {
            return wifi_error; // credentials saved, but timed out -> wifi error
        }
        else
        {
            return connect_ap; // no credentials -> connect to ap
        }
    }
    else if (server_active)
    {
        now_ms = millis();
        if (now_ms - server_start_time < SERVER_TIMEOUT)
        {
            return ip_address; // server active, not timed out -> show IP
        }
        else
        {
            return current_time; // server timed out -> show time
        }
    }
    else
    {
        set_touch_state(touch_state, previous_touch_state, touch_start, touch_end);

        time_t now = time(0);
        struct tm timeinfo = *localtime(&now);

        now_ms = millis();
        if (touch_state && now_ms - touch_start > SERVER_START)
        {
            server_start_time = millis();
            return ip_address; // held for long time -> start server
        }
        else if (!time_synced)
        {
            if (timeinfo.tm_year > 70)
            {
                time_synced = true;
            }
            return ntp_syncing; // time syncing -> show boot
        }
        else if (is_night(touch_state))
        {
            if (now_ms < SHOW_FOR + touch_wake_time)
            {
                // touched at night -> show time
                return current_time;
            }
            else
            {
                return in_sleep; // night -> clock off
            }
        }
        else
        {
            if ((now_ms < SHOW_FOR + touch_start) && !is_night())
            {
                return current_date; // touched during day -> show date
            }
            else
            {
                return current_time; // day -> show time
            }
        }
    }
}
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

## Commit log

2021-08-02 Preferences cancel button implemented
2021-08-04 KiCad files added
    [Calculations.ods, schematics.kicad_pcb, schematics.sch]
2021-08-04 5 power supply schematics drawn
    [schematics.sch]
2021-08-04 Boost converter schematic created
    [schematics.sch]
2021-08-06 Power management enabled
2021-08-06 Schematic footprints created
    [schematics.sch]
2021-08-09 Touch sensor fixed
2021-08-09 Schematics completed
    [schematics.kicad_pcb, schematics.sch]
2021-08-11 Main PCB completed
    [schematics.kicad_pcb, schematics.sch]
2021-08-16 Tube PCB wired
    [schematics.kicad_pcb, schematics.sch]
2021-08-17 Tube PCB created
    [schematics.kicad_pcb]
2021-08-24 Capacitor placements tweaked
    [schematics.kicad_pcb, schematics.sch]
2021-08-30 PCB finalized
    [schematics-B_Cu.gbl, schematics-B_Mask.gbs, schematics-B_Paste.gbp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]
2021-08-30 Gerber output folder renamed
    [schematics-B_Cu.gbl, schematics-B_Mask.gbs, schematics-B_Paste.gbp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]
2021-08-30 Gerber files moved to out folder
2021-09-08 Mesh files for case created
    [Case Bottom.3mf, Case Top.3mf]
2021-09-15 Variable declaration moved outside of case labels
2021-09-15 ESP32 drill holes widened, display angle set to 15
    [schematics_main.kicad_pcb, schematics_tube.kicad_pcb]
2021-09-26 Wiring fixed
    [schematics.kicad_pcb, schematics.sch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]
2021-09-26 Add to gitignore
    [Calculations.ods]
2021-09-26 .gitignore is now working
    [2021-07-03T152740.csv, Calculations.ods]
2021-09-29 Revision 2 of PCB, hopefully without workarounds
    [schematics.kicad_pcb, schematics.sch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]
2021-10-05 Create a bit more space for tube board header
    [Case Bottom.3mf, Case Top.3mf]
2021-10-20 Update blank input to PWM
2021-10-25 Added moving average for LDR, brightness fixed
    [display.cpp, init.cpp, main.cpp]
2021-10-28 Deep sleep wake-up fixed
    [display.cpp, init.cpp]
2021-10-28 Default brightness change fixed
    [main.cpp]
2021-10-29 Night mode fixed more
    [display.cpp]
2021-11-01 Made more robust against wifi connection errors
    [config_server.cpp, display.cpp, init.cpp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]
2021-11-04 Made factory reset work consistently
    [config_server.cpp]
2021-12-30 updated to KiCad 6
    [schematics.kicad_pcb, schematics.kicad_sch]
2021-12-30 PDFs added for easy viewing of PCB design
2022-02-10 added CAD file
    [Callisto.step]
